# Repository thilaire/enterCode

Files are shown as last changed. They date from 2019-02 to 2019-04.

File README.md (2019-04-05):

# enterCode

This is a small toy for my children:
- they want a small keyboard to "simulate" a code to enter their room
- a green LED will light on when the code is correct (red if not)
- they will also be able to use a RFID key

It is powered by three AA battery, and should not consume too much (sleep mode)

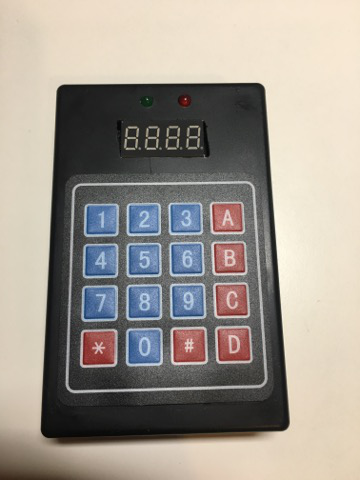
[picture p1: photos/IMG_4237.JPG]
enterCode box


# Principle

# Bill of Material
- an AVR micro-controller (ATtiny 2313)
- a small 4x4 matrix keyboard (
- 3 AA 1.5v battery (and their holder)
- two LEDs (green and red)
- a plastic box
- a RC522 RFID reader and some RFID key
- four 7-segment displays, with TM1637 driver

# Some links
- [doc for the RC522 board](https://www.sunrom.com/p/mifare-rfid-readerwriter-1356mhz-rc522)

# To Do (not yet done, but will be done... one day in the future)
- go to sleep mode after 20 seconds (when not used)
- RFID part

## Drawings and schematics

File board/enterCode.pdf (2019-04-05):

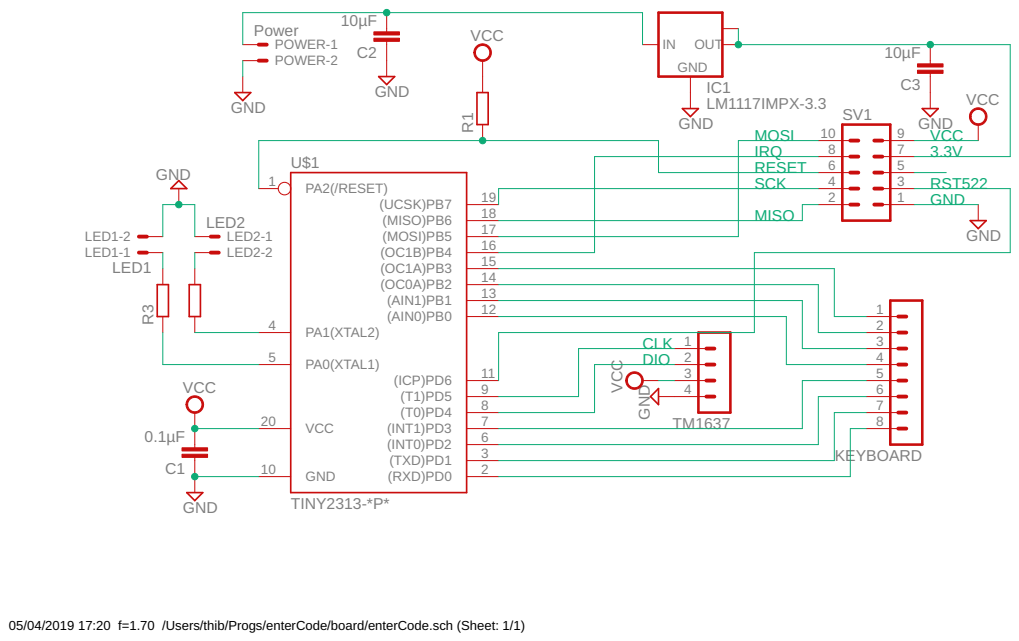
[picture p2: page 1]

14
13
12

05/04/2019 17:20 f=1.70 /Users/thib/Progs/enterCode/board/enterCode.sch (Sheet: 1/1)

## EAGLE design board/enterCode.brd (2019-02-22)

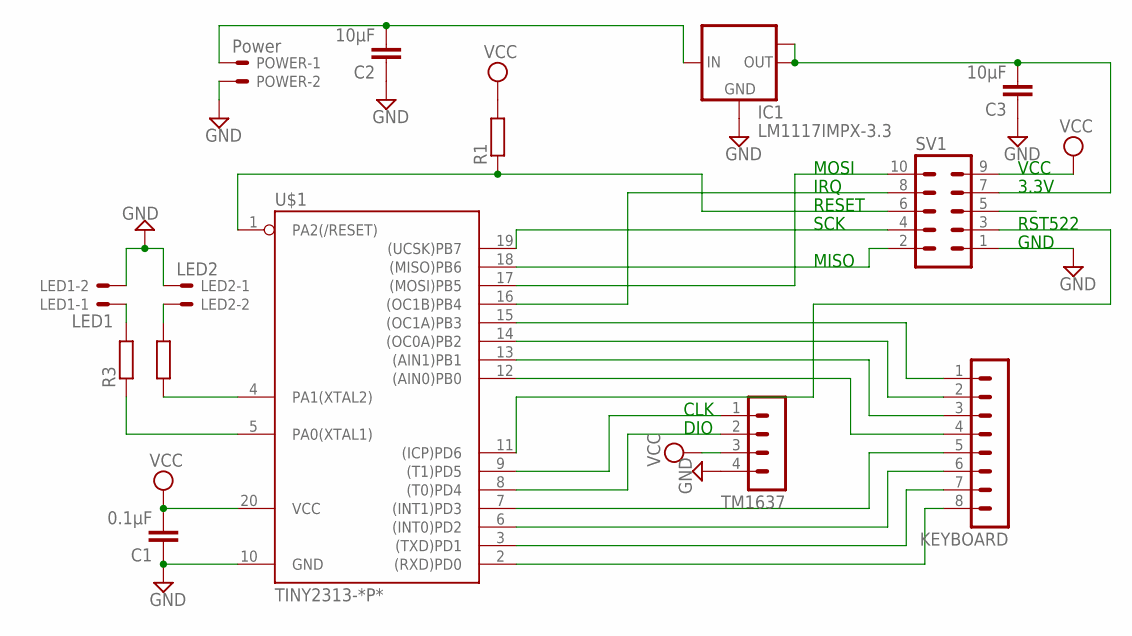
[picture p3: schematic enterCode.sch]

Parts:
C1: 0.1µF; C2.5-4
C2, C3: 10µF; C2.5-4
IC1: LM1117IMPX-3.3; SOT223
KEYBOARD: MA08-1
LED1: LED1; 22-23-2021
LED2: LED2; 22-23-2021
POWER: Power; 22-23-2021
R1: 10k; 0207/10
R2, R3: 470; 0207/10
SV1: MA05-2
TM1637: MA04-1
U$1: TINY2313-*P*; DIL20

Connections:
3.3V: C3.2, IC1.2 (OUT), IC1.TAB (OUT1), SV1.7
+5V: C2.2, IC1.3 (IN), POWER.1
GND: C1.1, C2.1, C3.1, IC1.1 (GND), LED1.2, LED2.1, POWER.2, SV1.1, TM1637.4, U$1.10 (GND)
MISO: SV1.2, U$1.18 ((MISO)PB6)
MOSI: SV1.10, U$1.17 ((MOSI)PB5)
unnamed: LED1.1, R3.2
unnamed: LED2.2, R2.2
PA0: R3.1, U$1.5 (PA0(XTAL1))
PA1: R2.1, U$1.4 (PA1(XTAL2))
PB0: KEYBOARD.4, U$1.12 ((AIN0)PB0)
PB1: KEYBOARD.3, U$1.13 ((AIN1)PB1)
PB2: KEYBOARD.2, U$1.14 ((OC0A)PB2)
PB3: KEYBOARD.1, U$1.15 ((OC1A)PB3)
PB4: SV1.8, U$1.16 ((OC1B)PB4)
PD0: KEYBOARD.8, U$1.2 ((RXD)PD0)
PD1: KEYBOARD.7, U$1.3 ((TXD)PD1)
PD2: KEYBOARD.6, U$1.6 ((INT0)PD2)
PD3: KEYBOARD.5, U$1.7 ((INT1)PD3)
PD4: TM1637.2, U$1.8 ((T0)PD4)
PD5: TM1637.1, U$1.9 ((T1)PD5)
PD6: SV1.3, U$1.11 ((ICP)PD6)
RESET: R1.1, SV1.6, U$1.1 (PA2(/RESET))
SCK: SV1.4, U$1.19 ((UCSK)PB7)
VCC: C1.2, R1.2, SV1.9, TM1637.3, U$1.20 (VCC)

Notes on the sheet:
CLK
DIO
RESET
SCK
MISO
IRQ
RST522
3.3V
GND
MOSI
VCC

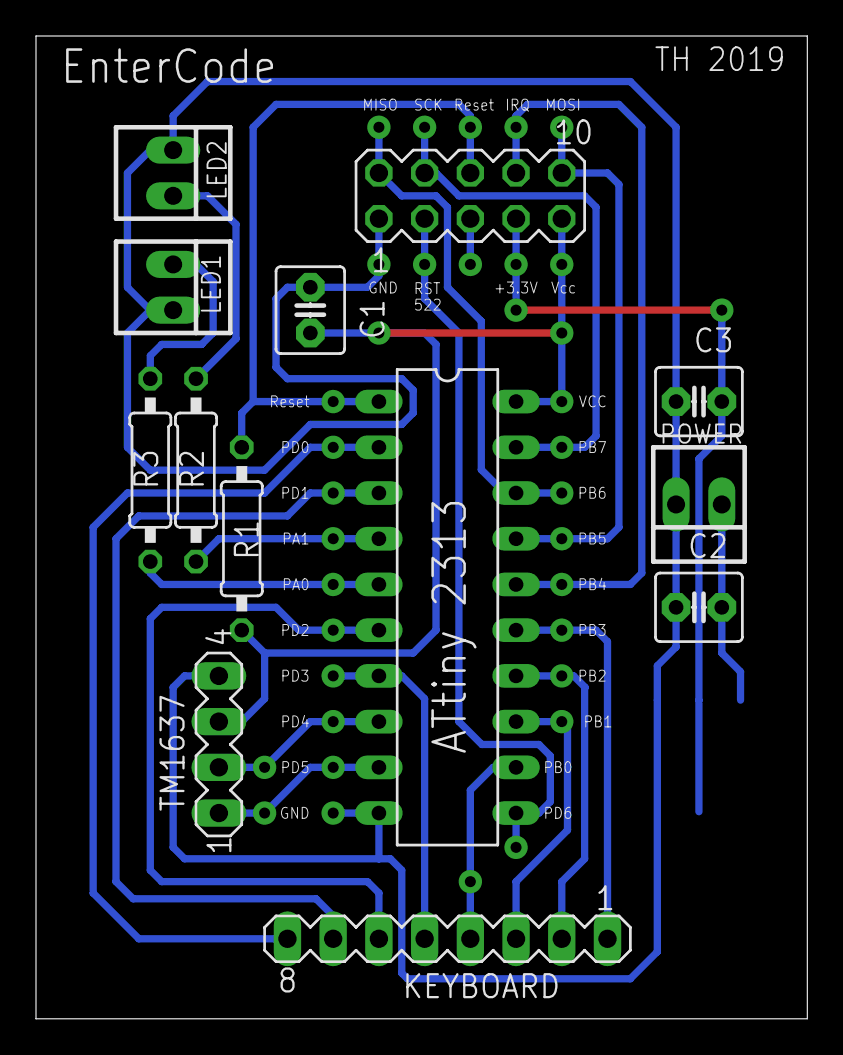
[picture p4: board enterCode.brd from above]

Board: 2 copper layers, 42.8 x 54.6 mm, 14 parts (1 on the bottom side), 24 nets.

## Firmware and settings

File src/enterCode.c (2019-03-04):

/*----------------------------------------------------------------------------

                          *============*
                          |            |
                          | enterCode  |
                          |            |
                          *============*


 Authors: T. HILAIRE
 Licence: GPL v3

 File: enterCode.c
       main function for the enterCode project
       - wait for a key, and turn on/off LEDs accordingly


Copyright 2019 T. Hilaire

----------------------------------------------------------------------------*/


#include <util/delay.h>
#include <avr/io.h>
#include <avr/eeprom.h>

#include "enterCode.h"
#include "TM1637.h"
#include "codes.h"


/* input/output
 * PA0: (out) LED1 (red)            PB0: (out) Keyboard 0
 * PA1: (out) LED2 (green)          PB1: (out) Keyboard 1
 * PD0: (in) Keyboard 0             PB2: (out) Keyboard 2
 * PD1: (in) Keyboard 1             PB3: (out) Keyboard 3
 * PD2: (in) Keyboard 2             PB4: (in) RS522 IRQ
 * PD3: (in) Keyboard 3             PB5: (out) SPI MOSI
 * PD4: (out) TM1637 DIO            PB6: (out) SPI MISO
 * PD5: (out) TM1637 CLK            PB7: (out) SPI SCK
 * PD6: (???) RS522
*/



const uint8_t NUMBER_FONT[] = {
		0b00111111, // 0
		0b00000110, // 1
		0b01011011, // 2
		0b01001111, // 3
		0b01100110, // 4
		0b01101101, // 5
		0b01111101, // 6
		0b00000111, // 7
		0b01111111, // 8
		0b01101111, // 9
		0b01110111, // A
		0b01111100, // B
		0b00111001, // C
		0b01011110, // D
		0b01111001, // E
		0b01110001  // F
};


const uint8_t CODE_CHAR[] = {
		0b00000110, // 1
		0b01011011, // 2
		0b01001111, // 3
		0b01110111, // A
		0b01100110, // 4
		0b01101101, // 5
		0b01111101, // 6
		0b01111100, // B
		0b00000111, // 7
		0b01111111, // 8
		0b01101111, // 9
		0b00111001, // C
		0,
		0b00111111, // 0
		0,
		0b01011110, // D
		0
};





int main()
{
	uint8_t key;							/* key hit on the keyboard */
	uint8_t accessCode[CODE_SIZE + 4];			/* actual code the user is typing on the keyboard */
	uint8_t pos = 4;						/* position of the next char (the 4 char are NO_KEY) */
	uint8_t codes[NB_CODES][CODE_SIZE];		/* array of valid codes (#0 is the master code) */
	uint8_t nC;								/* code number */
	uint8_t status = ACCESS_MODE;

    /* input/output config */
	DDRA = 0b00000011;       /* PA0 and PA1 are output */
    DDRB = 0b11101111;       /* PB4 is input, other are output */
    DDRD = 0b11110000;       /* PD0 to PD4 are input */
    PORTD = 0b00001111;		 /* PD0 to PD4 with pull-up */

    /* import the codes */
	//readCodesEEPROM(codes);
	eeprom_read_block(&(codes[0][0]), (uint8_t*)0, NB_CODES*CODE_SIZE);

    /* init code */
	for(uint8_t i=0; i<CODE_SIZE+4; i++)
		accessCode[i] = NO_KEY;

    /* init message */
    TM1637_setup(5);
    TM1637_write4(0b00111001, 0b00111111, 0b01011110, 0b01111001);	/* COdE */
	PORTA |= 0b00000011;
	_delay_ms(3000);
	PORTA &= ~0b00000011;
	TM1637_setup(5);

	/* main loop */
	while(1){
		/* wait */
		key = waitForKey();
		/* manage the key */
		if (key == KEY_SHARP) {
			/* validation of the code */
			if (status == ACCESS_MODE) {
				/* NORMAL MODE */
				nC = checkCode(codes, accessCode);
				/* reset code and display*/
				for (uint8_t i=0; i < CODE_SIZE+4; i++)
					accessCode[i] = NO_KEY;
				TM1637_write4(0, 0, 0, 0);
				pos = 4;
				/* check what to do now */
				if (nC ==0) {
					/* the master code has been entered */
					status = MASTER_MODE;
					pos = 0;
					/* turn on the two LEDs */
					PORTA |= 0b00000011;
				}
				else if (nC != 255) {
					/* display the number */
					TM1637_write4(NUMBER_FONT[nC], 64, 64, 64);
					/* green led */
					PORTA |= 0b00000010;
					_delay_ms(2000);
					PORTA &= ~0b00000010;
					TM1637_write4(0,0,0,0);
				} else {
					/* red led */
					PORTA |= 0b00000001;
					_delay_ms(2000);
					PORTA &= ~0b00000001;
				}
			} else {
				/* MASTER MODE */
				/* turn off the two LEDs */
				PORTA &= ~0b00000011;
				/* update the code and write in the EEPROM */
				updateCode(codes, accessCode);
				//writeCodesEEPROM(codes);
				eeprom_update_block(&(codes[0][0]), (uint8_t*)0, NB_CODES*CODE_SIZE);
				/* reset code and display */
				for (uint8_t i=0; i < CODE_SIZE+4; i++)
					accessCode[i] = NO_KEY;
				TM1637_write4(0, 0, 0, 0);
				pos = 4;
				/* green light to tell that it's ok */
				PORTA |= 0b00000010;
				_delay_ms(1000);
				PORTA &= ~0b00000010;
				status = ACCESS_MODE;
			}
		}
		else if (key == KEY_AST) {
			/* delete the last key */
			if (pos>4)
				pos--;
			accessCode[pos] = NO_KEY;
			TM1637_write4(CODE_CHAR[accessCode[pos-4]], CODE_CHAR[accessCode[pos-3]], CODE_CHAR[accessCode[pos-2]], CODE_CHAR[accessCode[pos-1]]);
		}
		else if ( (key != NO_KEY) && (pos<(4+CODE_SIZE)) ) {
			/* store the new key */
			accessCode[pos] = key;
			/* skip to the 4th key if we are in MASTER MODE and 1st char */
			if (pos==0) {
				pos = 3;
			}
			/* display */
			TM1637_write4(CODE_CHAR[accessCode[pos-3]], CODE_CHAR[accessCode[pos-2]], CODE_CHAR[accessCode[pos-1]], CODE_CHAR[key]);
			pos++;
		}

		_delay_ms(500);
	}

}

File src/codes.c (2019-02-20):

/*----------------------------------------------------------------------------

                          *============*
                          |            |
                          | enterCode  |
                          |            |
                          *============*


 Authors: T. HILAIRE
 Licence: GPL v3

 File: codes.c
       some functions to deal with the codes (check, change)


Copyright 2019 T. Hilaire

----------------------------------------------------------------------------*/


#include <util/delay.h>
#include <avr/io.h>
#include <avr/cpufunc.h>

#include "codes.h"


/* check if the code is correct
 * returns 255 if the code is not correct, otherwise return the code number*/
uint8_t checkCode(uint8_t codes[NB_CODES][CODE_SIZE], uint8_t accessCode[CODE_SIZE]) {
	/* check individually each code */
	for(uint8_t i=0; i<NB_CODES; i++) {
		uint8_t j=4;
		while ((accessCode[j]==codes[i][j-4]) && (accessCode[j] != NO_KEY))
			j++;
		if (accessCode[j]==codes[i][j-4])
			return i;
	}
	/* otherwise, the code is not equal to one of the codes */
	return 255;
}

/* returns the number of the 1st bit set to 0
 * x MUST BE non null */
uint8_t getZeroBit(uint8_t x)
{
	uint8_t line = 0;
	while (x&1) {
		x >>= 1;
		line++;
	}
	return line;
}



/* main function: wait for a key, and return the key character
 *
 * the NOP after each PORTB changes is *required*
 * */
uint8_t waitForKey(){
	uint8_t line, col;

	/* set the output lines to 0 */
	PORTB &= ~(0b00001111);
	_NOP();
	/* wait for a key and get the line*/
	//TODO: use interrupt !!
	while ((PIND&15) == 15);
	line = getZeroBit(PIND&15);
	/* wait for debounce (useful?) */
	_delay_ms(100);
	/* get column number, by toggling each column */
	PORTB |= 0b00001111;_NOP();
	for(col=0; col<4; col++) {
		PORTB &= ~(1<<col);
		_NOP();_NOP();
		if ((PIND&15) != 15)
			break;
		PORTB |= 0b00001111;
		_NOP();
	}
	if (col==4)
		return NO_KEY;

	/* wait the key is released */
	PORTB &= ~(0b00001111);
	_NOP();
	while((PIND&15) != 15);

	return (line<<2) + col;
}

/* update a code */
void updateCode(uint8_t codes[NB_CODES][CODE_SIZE], uint8_t accessCode[CODE_SIZE]) {
	uint8_t iC;	/* index of the code to be updated */

	/* get the number of the code to change (first byte at pos 0 is the key of the code) */
	iC = (accessCode[0]==KEY_ZERO) ? 0 : (accessCode[0] - ((accessCode[0]>>2)&3) + 1);

	/* change the code, if possible */
	if (iC < NB_CODES) {
		for (uint8_t i = 0; i < CODE_SIZE; i++)
			codes[iC][i] = accessCode[i + 4];
	}
}

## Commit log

2019-02-06 add the board
    [enterCode.brd, enterCode.sch]
2019-02-19 add pdf for the schematic
2019-02-19 reset code when validated with `#`
    [enterCode.c]
2019-02-19 add the Makefile (`make fuses` to program the fuses the 1st time, `make program` to program the ATtiny, and `make eeprom` to import the 1st EEPROM with 123456 as master code)
2019-02-22 Correct a MAJOR error in the design: the TAB of the regulator LM1117-3.3V is not corrected to GND (as it was) *but* to 3.3V signal !!
    [enterCode.brd, enterCode.sch]
2019-03-04 turn on the two LEDs during initialization
2019-03-04 adjust the delays so that it works under 3.3V !!
